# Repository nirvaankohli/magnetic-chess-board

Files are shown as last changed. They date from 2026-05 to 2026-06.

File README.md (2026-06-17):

# Magnetic Chess Board

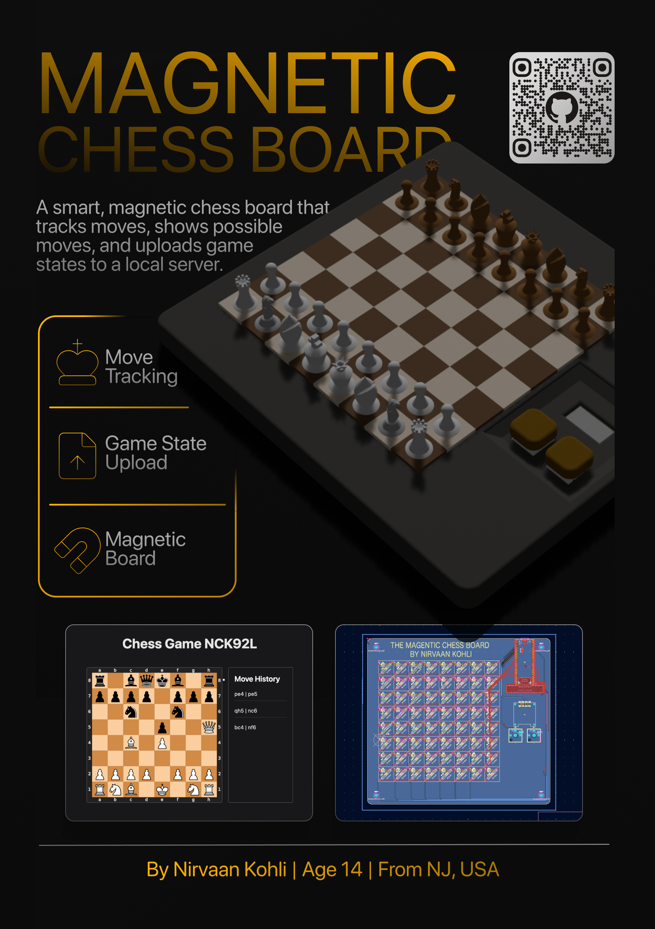
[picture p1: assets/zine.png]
Zine


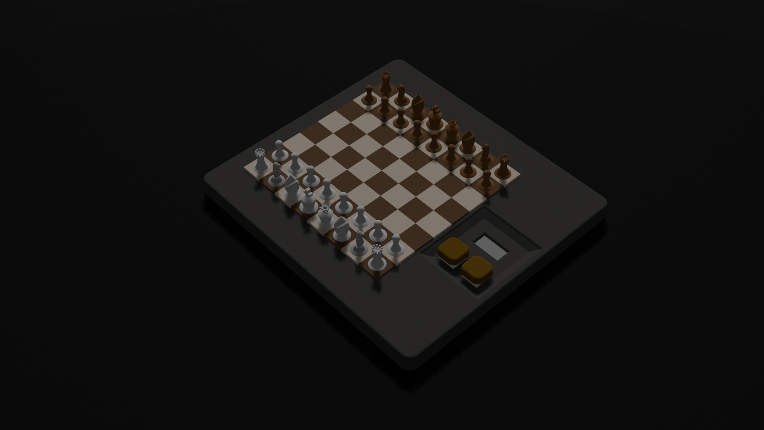
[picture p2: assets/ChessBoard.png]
Chess Board


---

## What is this project?

Magnetic Chess Board is a chessboard with electromagnetic sensors, two key switches, and an OLED display. It tracks each move you make on the board and uploads the game data to a local web server running on your device.

The chessboard itself is powered by a Raspberry Pi Pico W. The board connects wirelessly to your host device and allows you to play physically while having all the benefits of being able to analyze your gameplay later. Games are stored in json & svg format and can also be seen through the web interface on your own device.

---

## Why choose this project?

After creating [MORPH.00](https://github.com/nirvaankohli/MORPH.00/tree/main), a customizable keyboard that changes it's function, I wanted something different. Counsidently my feed showed me a chess board that can move the pieces itself. I orginally wanted to do this because of that video. However, I quickly found out the magic part of moving the pieces autonomously was to expensive. So, I settled for the next best thing, an electromagnetic chess board to analyze and track your moves. It was still such a cool idea because you are turning something physical into something digital. Additionally, let's say your friend comes voer and you play chess, you can expose the endpoint on like a server or something so both of you can look back at the game. Taking all of these things into account, I decided to choose this project. The use of this is legitimate because of the stuff I just mentioned above. 

----

This project is powered by a [Raspberry Pi Pico W](https://www.digikey.com/en/products/detail/raspberry-pi/SC0918/16608263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) running [MicroPython](https://micropython.org/download/RPI_PICO_W/) with some libraries. This microcontroller is on the top right part of the PCB so the charging port can be exposed and be close to components like the OLED and switches. 

The switches are low profile Choc V1 switches, the OLED a 0.96 Inch 128x64 OLED I2C Display Module, and all the electromagnetic sensors MKA-10110 10X18MM N/O SPST Contact Reed Switches. There is a part of this project on the host computer that hosts the web server that stores all the chess game's states and past move history. 

--- 

## CAD Renderings

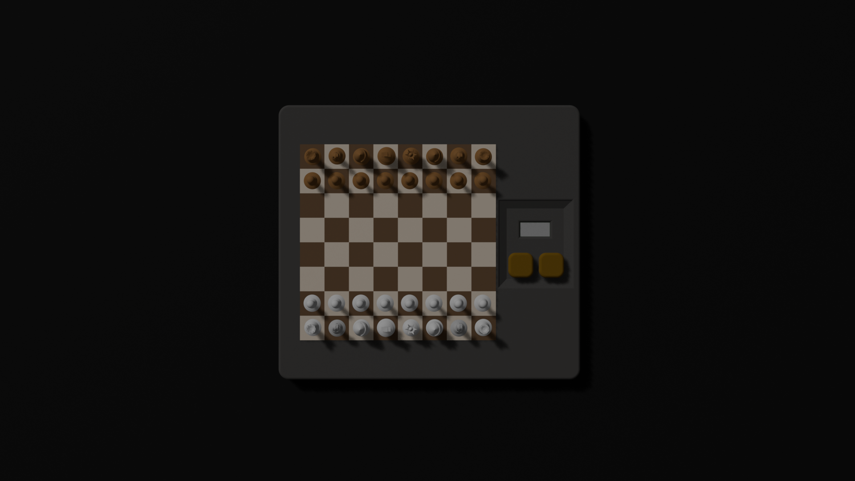
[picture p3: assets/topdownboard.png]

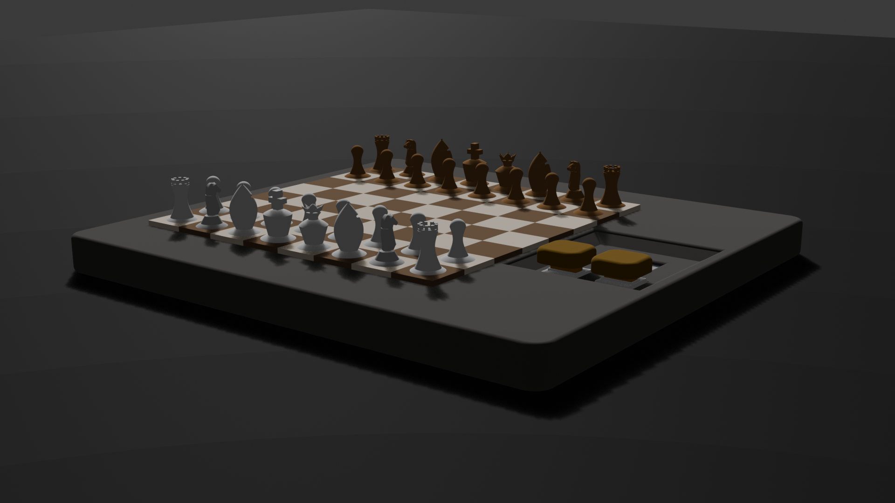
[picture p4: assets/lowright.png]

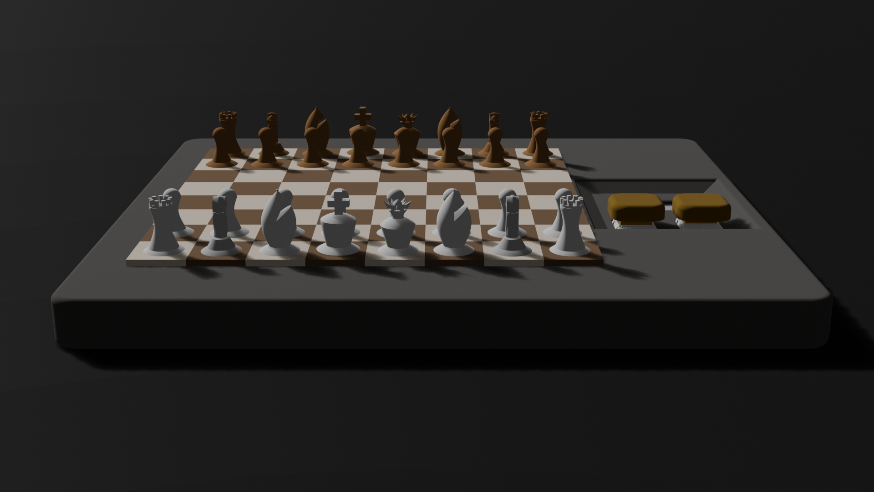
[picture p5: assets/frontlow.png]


My pieces 3D modeling is not the best, ik.

---

## PCB & Schematic

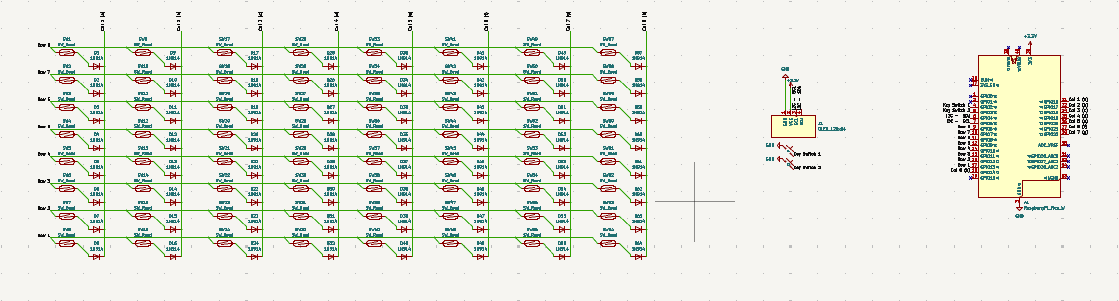
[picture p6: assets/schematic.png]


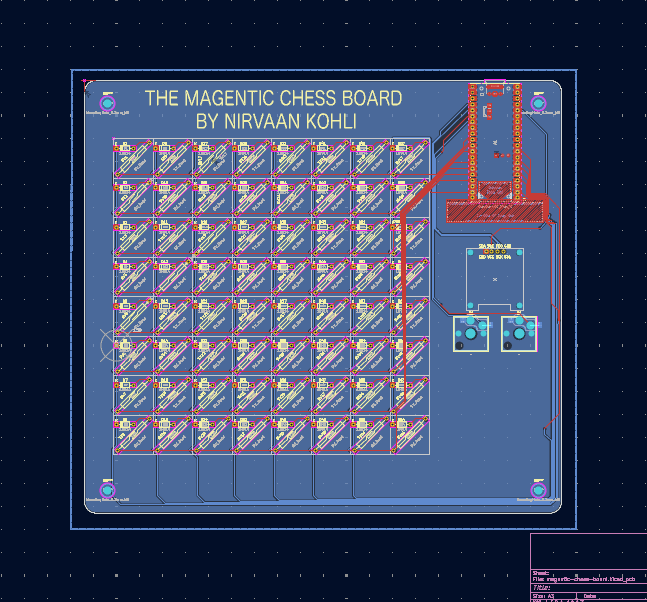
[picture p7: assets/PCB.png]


Below, is the PCB w components in multiple views.

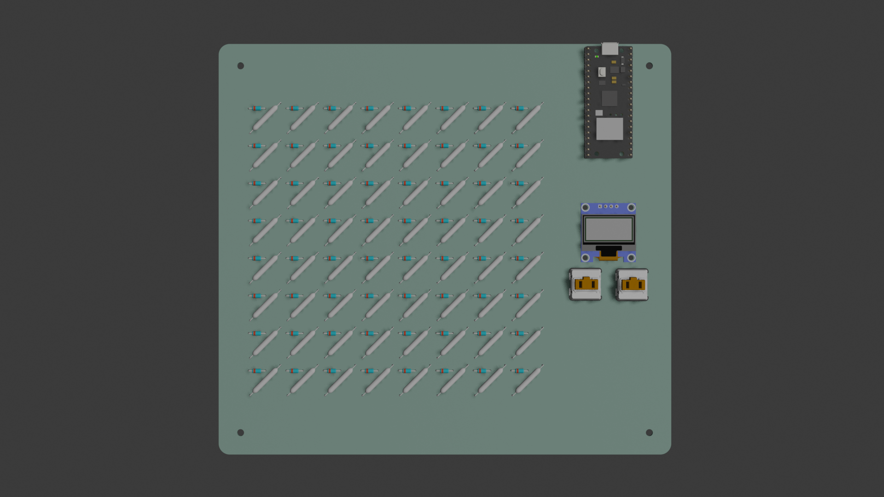
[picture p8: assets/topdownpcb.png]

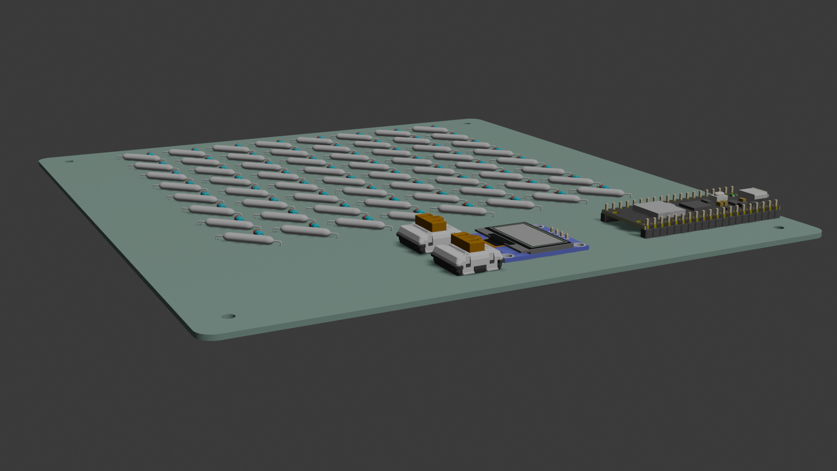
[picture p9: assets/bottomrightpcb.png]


Beautiful, right?

---

## Web Page

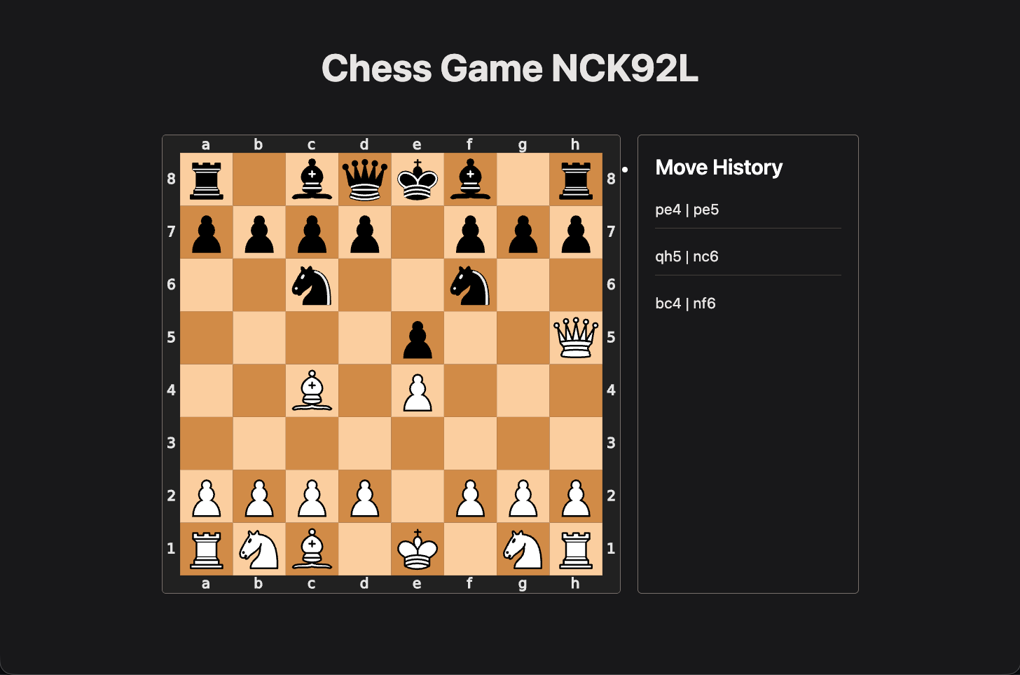
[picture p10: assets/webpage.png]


---

## How it Works

Each square on the board has a reed switch underneath it that detects wether a piece is present. A Raspberry Pi pico W scans all 8 columns and 8 rows of these switches as a key matrix, along with two buttons and an OLED display.

When a piece is moved the Pico W sends the current occupied squares to a local Flask server on the hosts computer(or anywhere). The server compares that physical board state to the saved chess game state(if the game was newly created it spins up a new one) using `python-chess`, finds the legal move that matches, and updates the game history. 

If the move is ambiguous, the OLED shows the possible moves and buttons let the player choose the correct one. After every valid move, the server saves the new board state and updates the web page so the full game can be viewed later.

---

## How To Use

1. Plug in a micro-usb cable into the Pico and the other end into your host computer
2. Install the firmware onto the Pico W(reference [this](code/pico_w/firmware.md) if not sure)
3. Download [the Thonny IDE](https://thonny.org/)
    - Click the bottom-right corner of Thonny and ensure it says MicroPython (Raspberry Pi Pico).
4. Update `code/pico_w/code/secrets.py` with:
    - your Wi-Fi SSID
    - your Wi-Fi password
    - your computer's local server address, like `http://192.168.x.x:5000`
5. In the Thonny Files sidebar, got to the "This computer" section to find the directory `code/pico_w/`. 
6. Right-click all the .py files and select `Upload to` to transfer the files to your pico.
7. Run the host server from `code/host`:
   ```bash
   flask --app app run --debug --host 0.0.0.0
    ```
8. Power on the board and wait for it to connect to WiFi.
9. Hold the white button to start a game(left).
10. Move pieces on the board as usual.
11. The white button confirms the current player's turn.
12. If the board detects multiple possible moves, use the black button to cycle through them and the white button to confirm the correct one.
13. Open the game page in your browser at:
```
http://<your-computer-ip>:5000/game/<game_id>
```
    to view the move history and current board state.

The server saves each game's state in `code/host/game_state/<game_id>.json` and `code/host/game_state/<game_id>.svg`

---

## How to Build/Assemble

Notice: You will need a way to 3D print parts for this & also have to buy all materials from [bom](bom.csv)

1. Go into `hardware/cad/3d-printed/pieces/` and print all the `.stl` files it contains. Below are which ones to print two times. 
    - Print `rook.stl`, `knight.stl`, and `bishop.stl` 2 times each for both black and white.
    - Then print both `queen.stl` and `king.stl` 1 time each for both black and white.
    - Print `disk.stl`s 16 times each for both black & white.
2. For every piece you have printed, put in the N42 magnet in it and put super glue on the remaining space and magnet.
    - Apply superglue to the bottom of a disc that matches the piece’s color, then press it face down into the extra space in the piece’s hole.
3. After you have assembled the pieces, it is time to solder on the components to the PCB board. If you do not know which components match what footprint, please reference `hardware/cad/boards/boards-w-components.step`
4. After doing that you will have to put the top frame(`hardware/cad/3d-printed/top-plate.stl`) onto the board. It should snap in. 
5. Then you will attach the bottom plate(`hardware/cad/3d-printed/bottom-plate.stl`) with a combination of the 4 screw holes(where you will put in the screw and the nut on the other side) and super glue.
6. From there you will need to print out the key caps available in `hardware/cad/3d-printed/key-cap.stl`
6. Now your chess board should be ready to go!

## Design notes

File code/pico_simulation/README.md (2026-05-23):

# Pico Simulation

Simulates PICO behaviour so we can make sure code works

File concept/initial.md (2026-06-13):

# Initial Thoughts, Plans, Description, etc.

## Different Approaches

### Criteria

- Price - Higher Score = Less Price - Weighting(Depends bc if it's really expensive it's really low, but it doesn't matter that much since fallout)
- Accuracy - Very Important
- Time - Sweet spot of 30 Hours(although all these options can be less or more depending on how big you wanna go on the software side)
- Difficulty - Sweet spot of 5-7/10 = 9/10(confusing ik)

- Magnetic Sensors
  - Summary: So the idea is that you have indivual magnetic sensors below each of 64 squares. The downside about this is that technically you can't tell what piece is which. However, you can guess pretty well based on the last game state. That is probably why I will need a 2 key switchs + OLED to communicate with the user if the board is set up or not, game updates, etc.
  - Ratings
    - Price - 6/10
    - Accuracy - 9/10
    - Time - 9/10
    - 6-7/10 - (so 8.5/10)
- CV
  - Summary: So the idea is that there is a camera of some sorts above the board(or any angle technically) that sees pieces. The problem of this is that it is inconvienient as they need to set up a camera and it might not be as accurate
  - Ratings
    - Price - 10/10
    - Accuracy - 7.5/10
    - Time - 8/10
    - 4/10 so 6/10
  
## Verdict

Obviously magnetic sensors.

Let us just figure out what stuff is needed and what it will cost :O

- Reed Switch Magentic Switch - [2x14mm MKA14103 for 0.73/5 pieces](https://www.aliexpress.us/item/3256801651270926.html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) - getting 70 bc packaging is bad so total price + shipping - about $15
- With 8 rows & Columns using key matricies
- 2 keys
- A nob
- and 1 inch oleds

https://www.magnetshop.com/neodymium-disc-magnet-42dne0608-ni.html for magents

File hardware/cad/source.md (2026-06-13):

# Onshape Link
Link

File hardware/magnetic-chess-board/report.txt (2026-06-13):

Info: X scale constrained.
Info: Y scale constrained.
Plotted to '/Users/nirvaank/Code/Hardware/fallout/magnetic-chess-board/magnetic-chess-board/hardware/magnetic-chess-board/magnetic-chess-board-F_Cu.gbr'.
Plotted to '/Users/nirvaank/Code/Hardware/fallout/magnetic-chess-board/magnetic-chess-board/hardware/magnetic-chess-board/magnetic-chess-board-B_Cu.gbr'.
Plotted to '/Users/nirvaank/Code/Hardware/fallout/magnetic-chess-board/magnetic-chess-board/hardware/magnetic-chess-board/magnetic-chess-board-F_Paste.gbr'.
Plotted to '/Users/nirvaank/Code/Hardware/fallout/magnetic-chess-board/magnetic-chess-board/hardware/magnetic-chess-board/magnetic-chess-board-B_Paste.gbr'.
Plotted to '/Users/nirvaank/Code/Hardware/fallout/magnetic-chess-board/magnetic-chess-board/hardware/magnetic-chess-board/magnetic-chess-board-F_Silkscreen.gbr'.
Plotted to '/Users/nirvaank/Code/Hardware/fallout/magnetic-chess-board/magnetic-chess-board/hardware/magnetic-chess-board/magnetic-chess-board-B_Silkscreen.gbr'.
Plotted to '/Users/nirvaank/Code/Hardware/fallout/magnetic-chess-board/magnetic-chess-board/hardware/magnetic-chess-board/magnetic-chess-board-F_Mask.gbr'.
Plotted to '/Users/nirvaank/Code/Hardware/fallout/magnetic-chess-board/magnetic-chess-board/hardware/magnetic-chess-board/magnetic-chess-board-B_Mask.gbr'.
Plotted to '/Users/nirvaank/Code/Hardware/fallout/magnetic-chess-board/magnetic-chess-board/hardware/magnetic-chess-board/magnetic-chess-board-Edge_Cuts.gbr'.
Created Gerber job file '/Users/nirvaank/Code/Hardware/fallout/magnetic-chess-board/magnetic-chess-board/hardware/magnetic-chess-board/magnetic-chess-board-job.gbrjob'.
Info: Done.

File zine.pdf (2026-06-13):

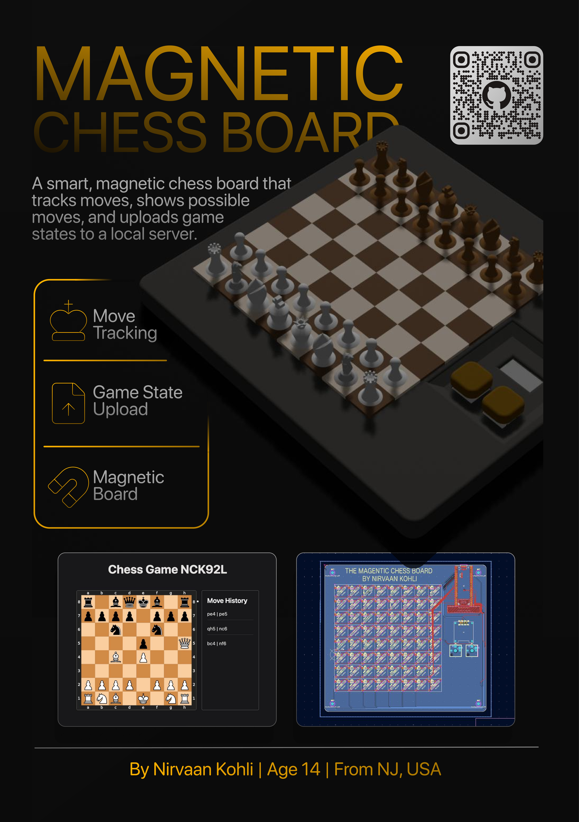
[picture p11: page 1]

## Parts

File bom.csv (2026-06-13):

Part Name | Part Number | Qty | Unit | Qty of Product | Unit Cost | Total Cost(w/o shipping) | Total/Final Cost(with shipping) | url
M3 x 5mm Socket Flat Head Screws | M3-0.5X5-FH-A2 | 4 | pcs | 1 | $3.75 | $4.69 | $4.69 | https://www.ebay.com/itm/297651673962?var=595006893034
Loctite Essentials Super Glue Liquid Tubes (0.11 oz tubes) | LOC-ESSENTIAL-3G-4PK-SG-LQ-H-TBE-12PG | 1 | tube | 1 | $0.72 | $2.88 | $9.87 | https://www.walmart.com/ip/seort/15670220393
N42 Neodymium Disc Magnet | 42DNE0608-NI | 64 | pcs | 64 | $19.20 | $19.20 | $19.20 | https://www.magnetshop.com/neodymium-disc-magnet-42dne0608-ni.html
Kailh 1350 Choc V1 Brown Switch(10 pcs) | CPG135001D02 | 2 | pcs | 10 | $1.48 | $7.40 | $7.40 | https://www.aliexpress.us/item/3256811626047380.html?curPageLogUid=gMyMy9GAItqi
20 PCS MKA-10110 10X18MM Magnetic Sensor N/O SPST Contact Reed Switches | CPG135001S30 | 64 | pcs | 4 | $22.05 | $27.56 | $33.30 | https://www.aliexpress.us/item/3256811899463529.html?curPageLogUid=F80mUPvjcfot
PLA 3D Printer Filament (1.75mm, 1kg Spool, Black) | B07XG3RM58 | 1 | spool | 1 | $13.99 | $13.99 | $13.99 | https://www.amazon.com/Printer-Filament-SUNLU-Dimensional-Accuracy/dp/B07XG3RM58?rnid=2661611011
0.96 Inch OLED Display Module (I2C/IIC/SPI Serial 128X64, SSD1315 Driver) | 1005009059402520 | 1 | pcs | 1 | $1.49 | $1.49 | $6.72 | https://www.aliexpress.us/item/3256808873087768.html?curPageLogUid=4nQOOlsmmnd3
RASPBERRY PI PICO W RP2040 | SC0918 | 1 | pcs | 1 | $6.00 | $6.00 | $15.09 | https://www.digikey.com/en/products/detail/raspberry-pi/SC0918/16608263?gclsrc=aw.ds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
CONN HEADER VERT 20POS 2.54MM | 10129378-920003BLF | 2 | pcs | 2 | $1.02 | $1.02 | $9.87 | https://www.digikey.com/en/products/detail/amphenol-icc-fci-/10129378-920003BLF/7915971?gclsrc=aw.ds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
Stainless Steel Hexagon Nuts (Fasteners Replacement) | B0DRF8FF5Z | 4 | pcs | 1 | $0.02 | $4.99 | $4.99 | https://www.amazon.com/Yinpecly-Stainless-Hexagon-Fasteners-Replacement/dp/B0DRF8FF5Z?rnid=386419011
PCB(JLCPCB) - 207.1 x 187.96 | None | 1 | pcs | 1 | $19.70 | $19.70 | $29.78 | https://cart.jlcpcb.com/quote?rand=0.17716329742027792

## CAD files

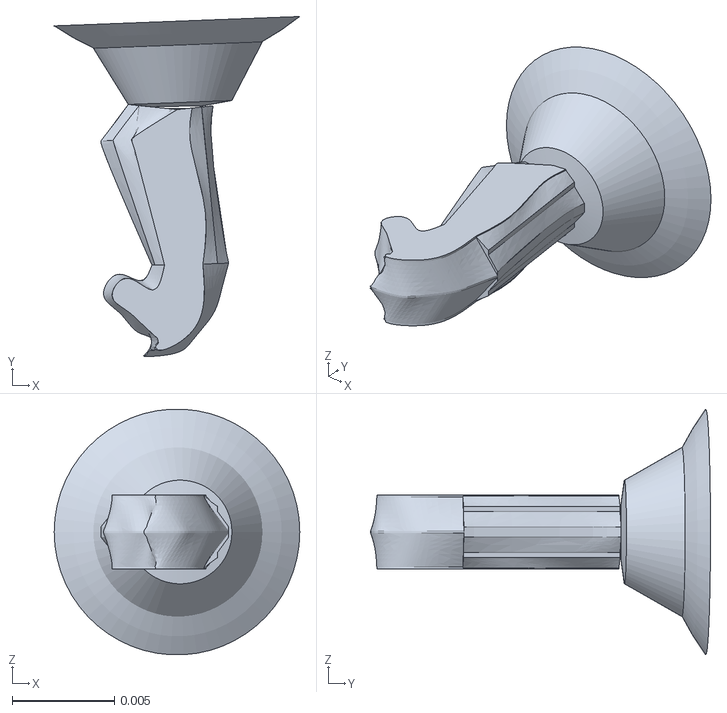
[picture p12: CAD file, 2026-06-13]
hardware/cad/3d-printed/pieces/knight.stl
0.012 x 0.0166 x 0.012

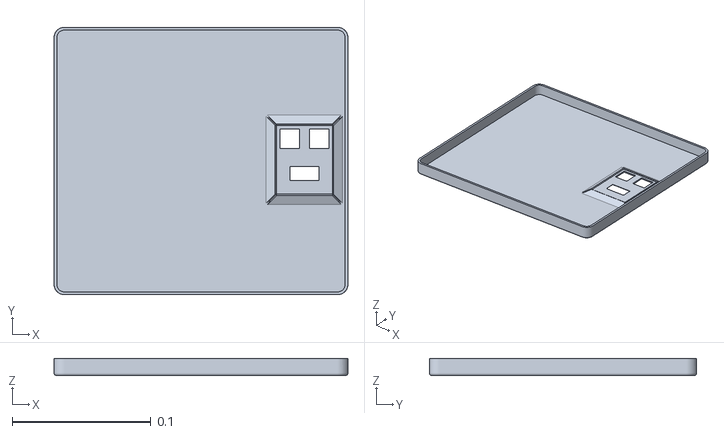
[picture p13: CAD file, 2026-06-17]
hardware/cad/3d-printed/top-plate.stl
0.212 x 0.193 x 0.0125

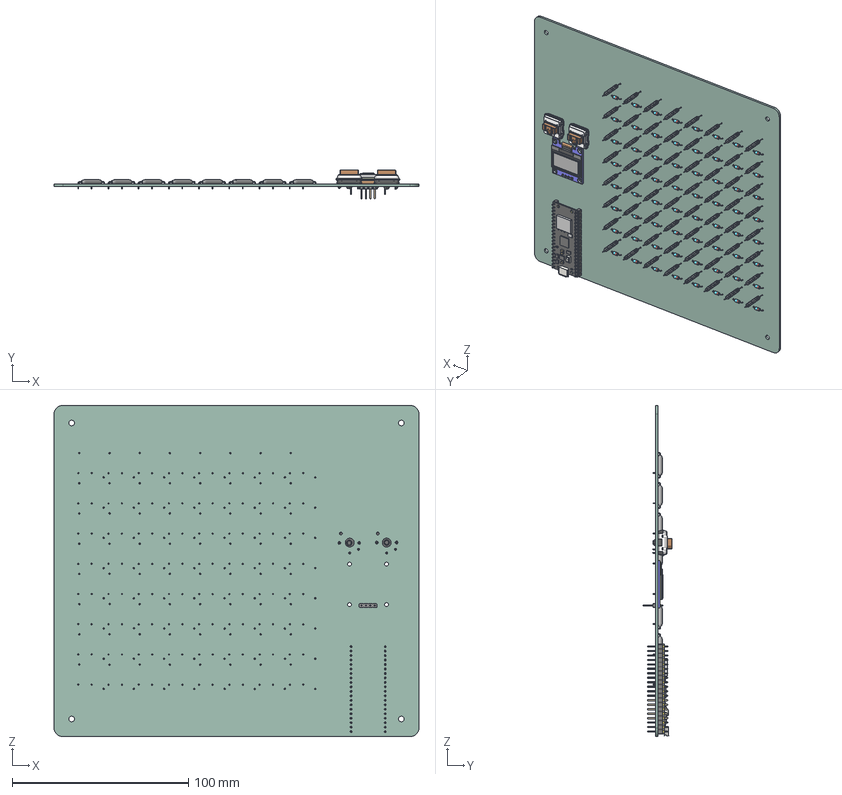
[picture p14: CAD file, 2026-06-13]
hardware/cad/boards/boards-w-components.step
207.1 x 16.6 x 188.0 mm
D_DO-35_SOD27_P7.62mm_Horizontal x 128
magnetic-chess-board_PCB
Root x 64
OLED x 50
Choc_V1 x 10
RaspberryPi_Pico_W_Module_KiCad
PinHeader_1x20_P2.54mm_Vertical x 2

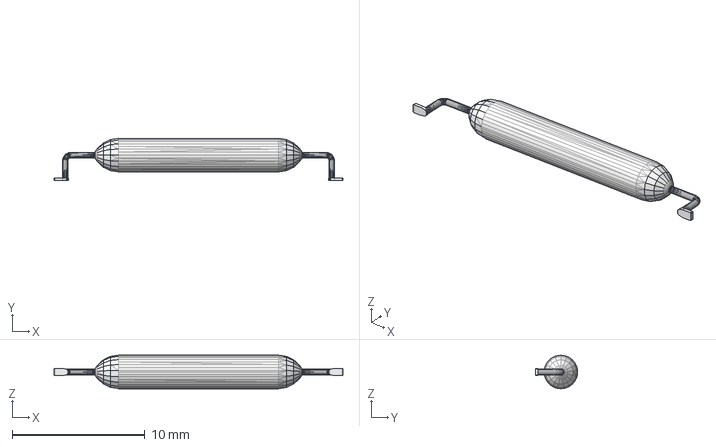
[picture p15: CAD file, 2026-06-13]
hardware/cad/components/MKA-14103.step
21.8 x 3.19 x 2.53 mm

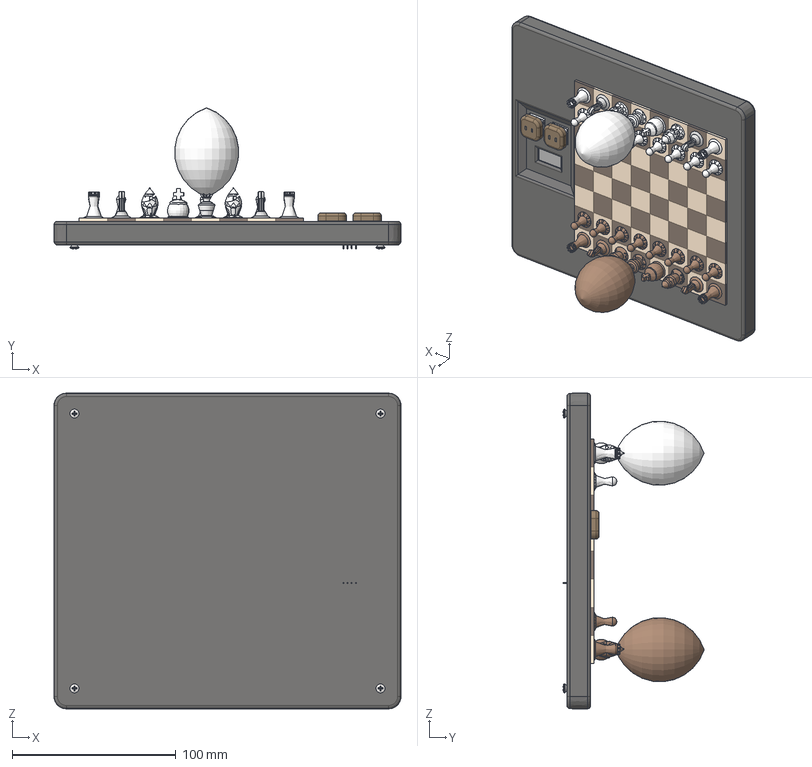
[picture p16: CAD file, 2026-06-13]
hardware/cad/final-build.step
212.1 x 86.5 x 193.0 mm
D_DO-35_SOD27_P7.62mm_Horizontal x 128
magnetic-chess-board_PCB
Root x 64
OLED x 50
Brown Square x 32
Tan Square x 32
Choc_V1 x 10
RaspberryPi_Pico_W_Module_KiCad
m3-5mm x 4
PinHeader_1x20_P2.54mm_Vertical x 2

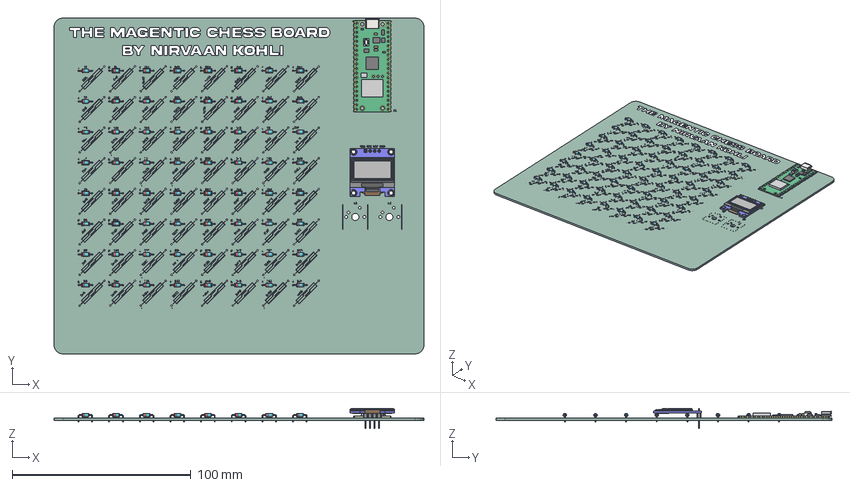
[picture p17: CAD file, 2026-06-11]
hardware/magnetic-chess-board/board.step
207.1 x 188.0 x 11.3 mm
D_DO-35_SOD27_P7.62mm_Horizontal x 64
OLED
RaspberryPi_Pico_W_Module_KiCad
magnetic-chess-board_silkscreen
magnetic-chess-board_PCB

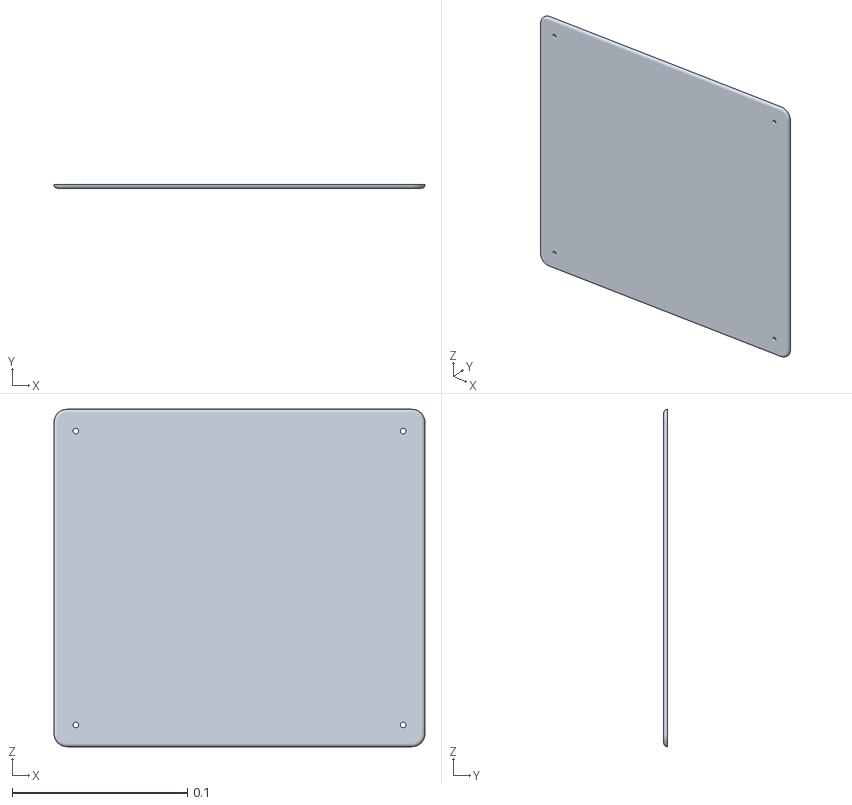
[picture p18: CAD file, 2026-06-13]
hardware/cad/3d-printed/bottom-plate.stl
0.212 x 0.002 x 0.193

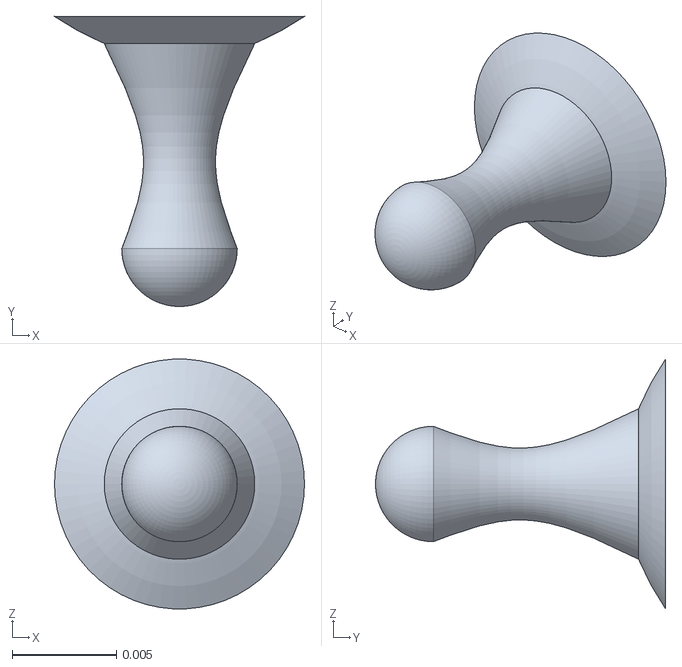
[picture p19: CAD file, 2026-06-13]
hardware/cad/3d-printed/pieces/pawn.stl
0.012 x 0.0139 x 0.012

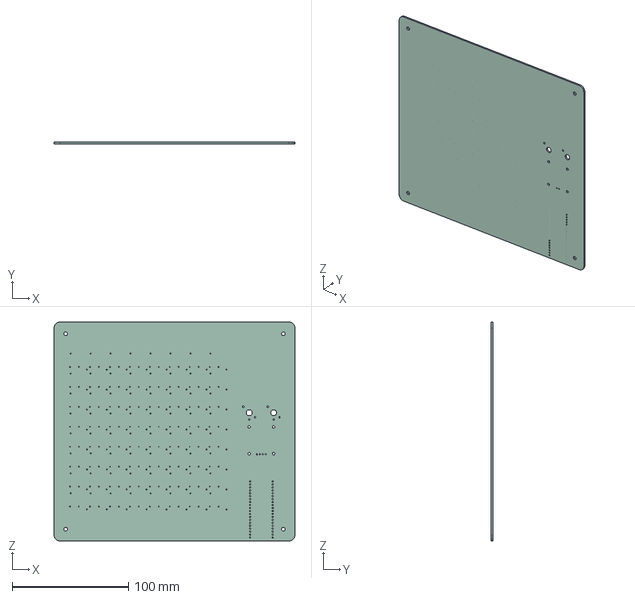
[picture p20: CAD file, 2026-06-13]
hardware/cad/boards/board.step
207.1 x 1.51 x 188.0 mm

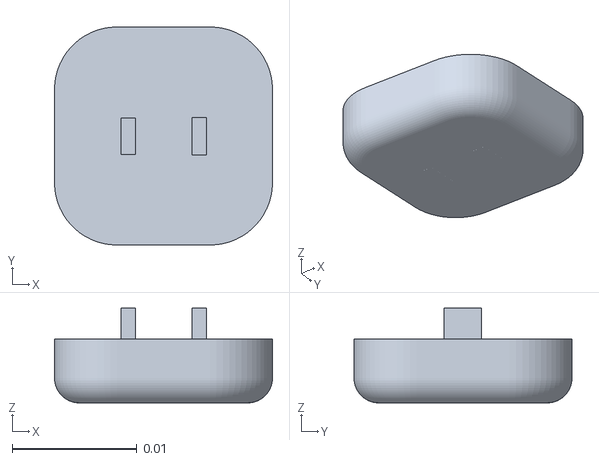
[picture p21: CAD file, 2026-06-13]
hardware/cad/3d-printed/key-cap.stl
0.0175 x 0.0175 x 0.00763

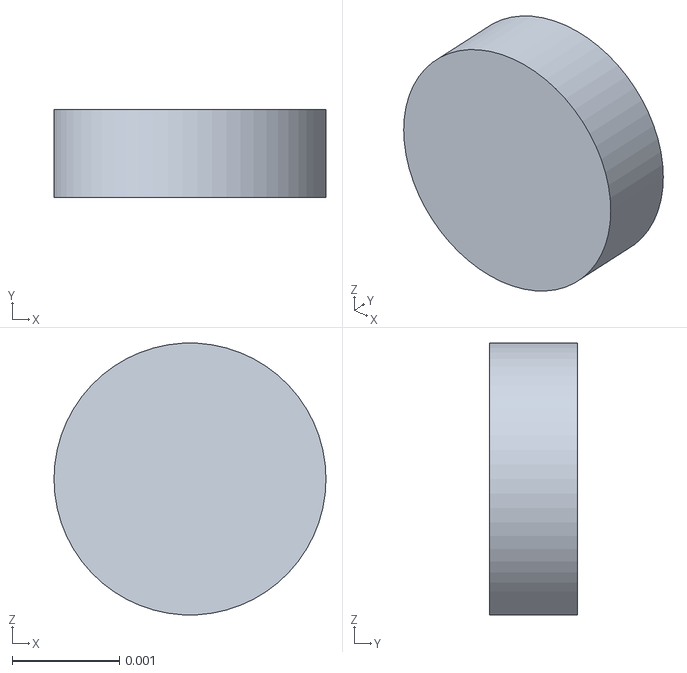
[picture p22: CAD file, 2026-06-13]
hardware/cad/3d-printed/pieces/disk.stl
0.00254 x 0.000825 x 0.00254

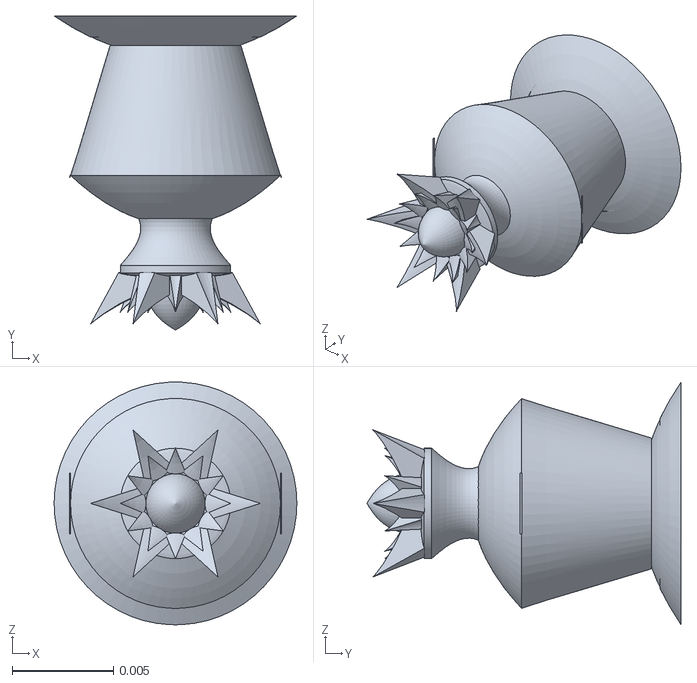
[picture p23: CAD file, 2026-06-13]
hardware/cad/3d-printed/pieces/queen.stl
0.012 x 0.0155 x 0.012

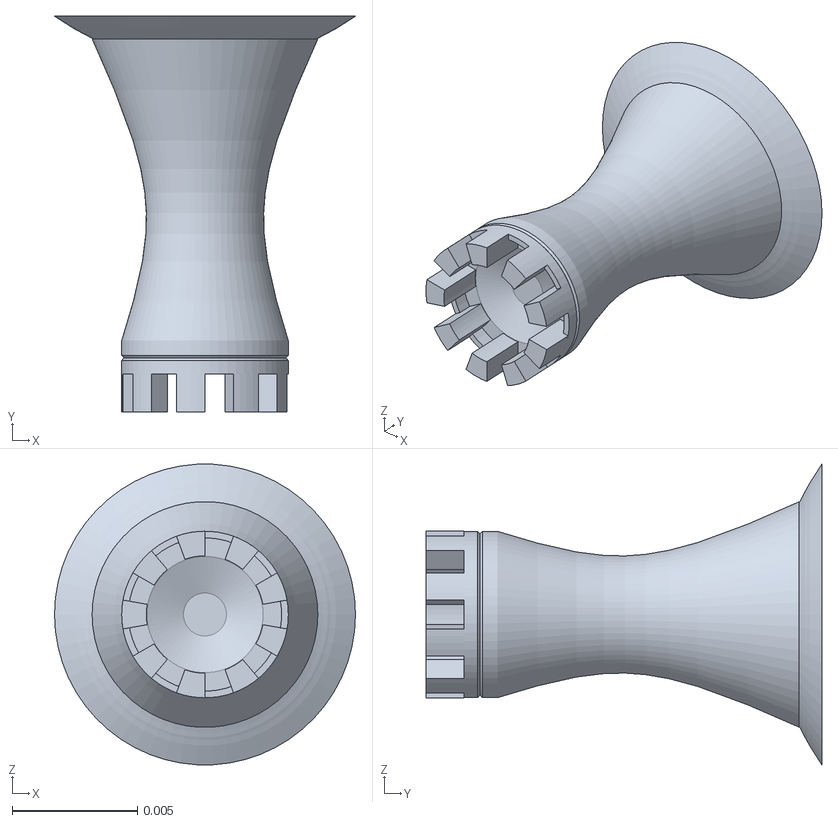
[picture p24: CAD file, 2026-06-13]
hardware/cad/3d-printed/pieces/rook.stl
0.012 x 0.0158 x 0.012

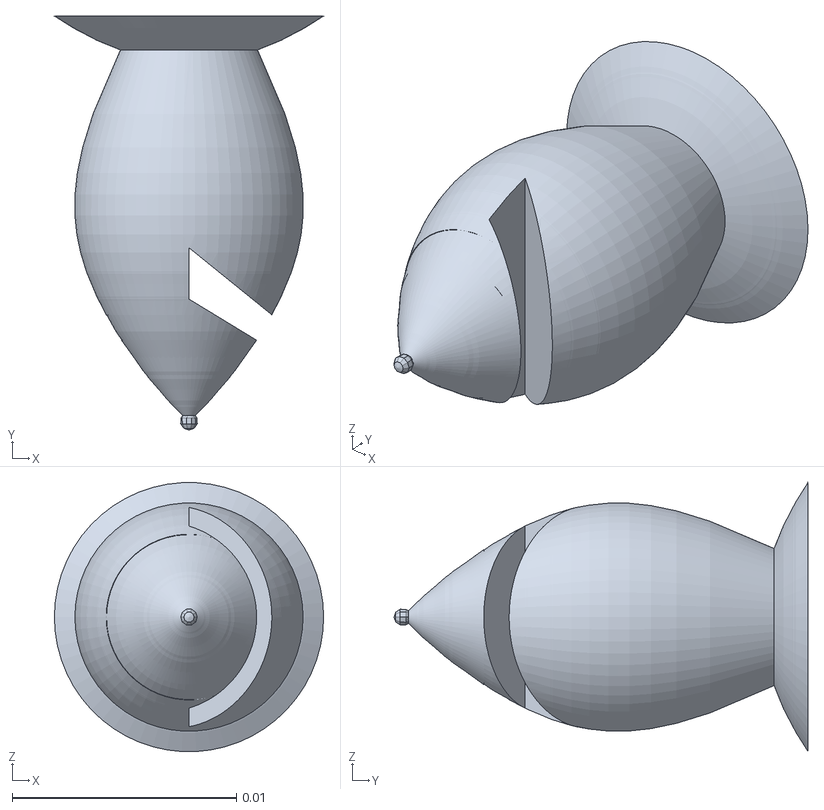
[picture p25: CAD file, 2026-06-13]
hardware/cad/3d-printed/pieces/bishop.stl
0.012 x 0.0185 x 0.012

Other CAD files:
hardware/magnetic-chess-board/board_only.step
hardware/cad/3d-printed/pieces/king.stl
hardware/cad/components/m3-5mm-screw.step

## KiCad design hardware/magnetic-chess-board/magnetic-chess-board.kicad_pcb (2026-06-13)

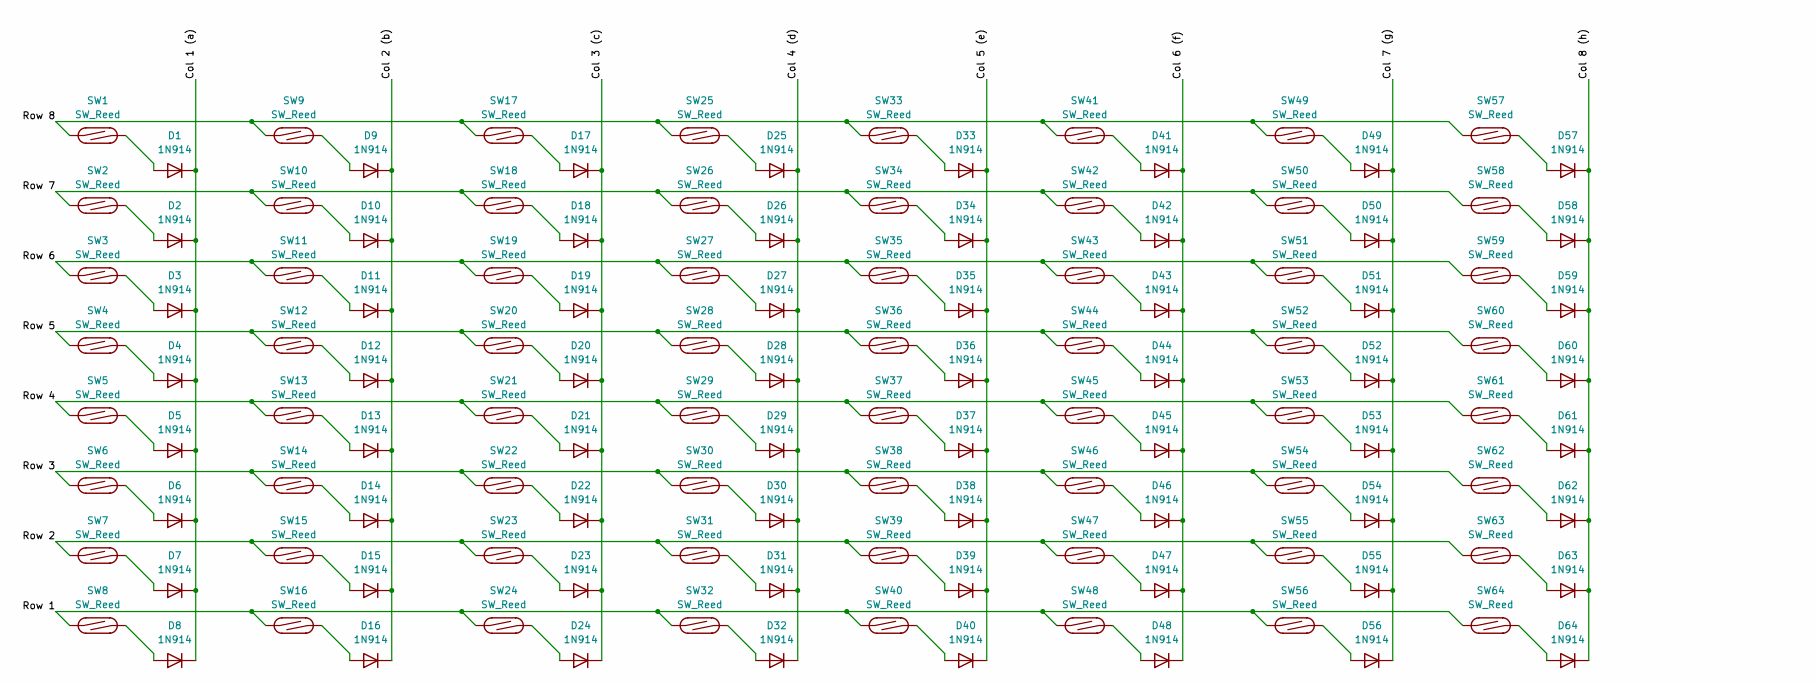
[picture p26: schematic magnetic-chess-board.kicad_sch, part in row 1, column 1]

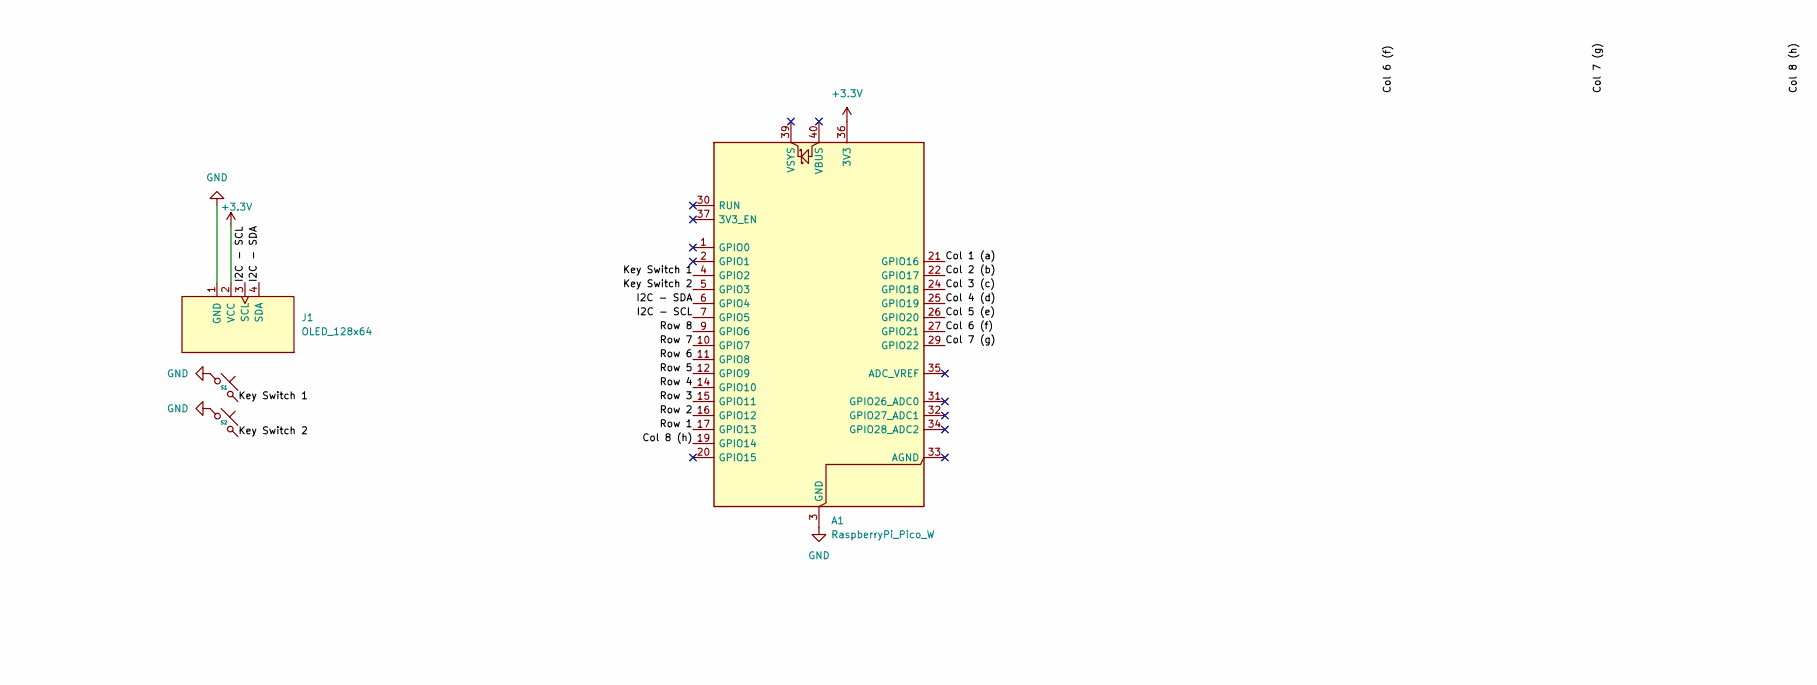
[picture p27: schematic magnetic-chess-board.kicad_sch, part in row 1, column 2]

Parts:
A1: RaspberryPi_Pico_W; RaspberryPi_Pico_W_SMD
D1, D2, D3, D4, D5, D6, D7, D8, D9, D10, D11, D12, D13, D14, D15, D16, D17, D18, D19, D20, D21, D22, D23, D24, D25, D26, D27, D28, D29, D30, D31, D32, D33, D34, D35, D36, D37, D38, D39, D40, D41, D42, D43, D44, D45, D46, D47, D48, D49, D50, D51, D52, D53, D54, D55, D56, D57, D58, D59, D60, D61, D62, D63, D64: 1N914; D_DO-35_SOD27_P7.62mm_Horizontal
J1: OLED_128x64
S1, S2: SW_Hotswap_Kailh_Choc_V1
SW1, SW2, SW3, SW4, SW5, SW6, SW7, SW8, SW9, SW10, SW11, SW12, SW13, SW14, SW15, SW16, SW17, SW18, SW19, SW20, SW21, SW22, SW23, SW24, SW25, SW26, SW27, SW28, SW29, SW30, SW31, SW32, SW33, SW34, SW35, SW36, SW37, SW38, SW39, SW40, SW41, SW42, SW43, SW44, SW45, SW46, SW47, SW48, SW49, SW50, SW51, SW52, SW53, SW54, SW55, SW56, SW57, SW58, SW59, SW60, SW61, SW62, SW63, SW64: SW_Reed; MKA-14103

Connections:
+3.3V: A1.36 (3V3), J1.2 (VCC)
/Col 1 (a): A1.21 (GPIO16), D1.1 (K), D2.1 (K), D3.1 (K), D4.1 (K), D5.1 (K), D6.1 (K), D7.1 (K), D8.1 (K)
/Col 2 (b): A1.22 (GPIO17), D9.1 (K), D10.1 (K), D11.1 (K), D12.1 (K), D13.1 (K), D14.1 (K), D15.1 (K), D16.1 (K)
/Col 3 (c): A1.24 (GPIO18), D17.1 (K), D18.1 (K), D19.1 (K), D20.1 (K), D21.1 (K), D22.1 (K), D23.1 (K), D24.1 (K)
/Col 4 (d): A1.25 (GPIO19), D25.1 (K), D26.1 (K), D27.1 (K), D28.1 (K), D29.1 (K), D30.1 (K), D31.1 (K), D32.1 (K)
/Col 5 (e): A1.26 (GPIO20), D33.1 (K), D34.1 (K), D35.1 (K), D36.1 (K), D37.1 (K), D38.1 (K), D39.1 (K), D40.1 (K)
/Col 6 (f): A1.27 (GPIO21), D41.1 (K), D42.1 (K), D43.1 (K), D44.1 (K), D45.1 (K), D46.1 (K), D47.1 (K), D48.1 (K)
/Col 7 (g): A1.29 (GPIO22), D49.1 (K), D50.1 (K), D51.1 (K), D52.1 (K), D53.1 (K), D54.1 (K), D55.1 (K), D56.1 (K)
/Col 8 (h): A1.19 (GPIO14), D57.1 (K), D58.1 (K), D59.1 (K), D60.1 (K), D61.1 (K), D62.1 (K), D63.1 (K), D64.1 (K)
/I2C - SCL: A1.7 (GPIO5), J1.3 (SCL)
/I2C - SDA: A1.6 (GPIO4), J1.4 (SDA)
/Key Switch 1: A1.4 (GPIO2), S1.2
/Key Switch 2: A1.5 (GPIO3), S2.2
/Row 1: A1.17 (GPIO13), SW8.1, SW16.1, SW24.1, SW32.1, SW40.1, SW48.1, SW56.1, SW64.1
/Row 2: A1.16 (GPIO12), SW7.1, SW15.1, SW23.1, SW31.1, SW39.1, SW47.1, SW55.1, SW63.1
/Row 3: A1.15 (GPIO11), SW6.1, SW14.1, SW22.1, SW30.1, SW38.1, SW46.1, SW54.1, SW62.1
/Row 4: A1.14 (GPIO10), SW5.1, SW13.1, SW21.1, SW29.1, SW37.1, SW45.1, SW53.1, SW61.1
/Row 5: A1.12 (GPIO9), SW4.1, SW12.1, SW20.1, SW28.1, SW36.1, SW44.1, SW52.1, SW60.1
/Row 6: A1.11 (GPIO8), SW3.1, SW11.1, SW19.1, SW27.1, SW35.1, SW43.1, SW51.1, SW59.1
/Row 7: A1.10 (GPIO7), SW2.1, SW10.1, SW18.1, SW26.1, SW34.1, SW42.1, SW50.1, SW58.1
/Row 8: A1.9 (GPIO6), SW1.1, SW9.1, SW17.1, SW25.1, SW33.1, SW41.1, SW49.1, SW57.1
GND: A1.3 (GND), A1.8 (GND), A1.13 (GND), A1.18 (GND), A1.23 (GND), A1.28 (GND), A1.38 (GND), J1.1 (GND), S1.1, S2.1
unnamed: D1.2 (A), SW1.2
unnamed: D2.2 (A), SW2.2
unnamed: D3.2 (A), SW3.2
unnamed: D4.2 (A), SW4.2
unnamed: D5.2 (A), SW5.2
unnamed: D6.2 (A), SW6.2
unnamed: D7.2 (A), SW7.2
unnamed: D8.2 (A), SW8.2
unnamed: D9.2 (A), SW9.2
unnamed: D10.2 (A), SW10.2
unnamed: D11.2 (A), SW11.2
unnamed: D12.2 (A), SW12.2
unnamed: D13.2 (A), SW13.2
unnamed: D14.2 (A), SW14.2
unnamed: D15.2 (A), SW15.2
unnamed: D16.2 (A), SW16.2
unnamed: D17.2 (A), SW17.2
unnamed: D18.2 (A), SW18.2
unnamed: D19.2 (A), SW19.2
unnamed: D20.2 (A), SW20.2
unnamed: D21.2 (A), SW21.2
unnamed: D22.2 (A), SW22.2
unnamed: D23.2 (A), SW23.2
unnamed: D24.2 (A), SW24.2
unnamed: D25.2 (A), SW25.2
unnamed: D26.2 (A), SW26.2
unnamed: D27.2 (A), SW27.2
unnamed: D28.2 (A), SW28.2
unnamed: D29.2 (A), SW29.2
unnamed: D30.2 (A), SW30.2
unnamed: D31.2 (A), SW31.2
unnamed: D32.2 (A), SW32.2
unnamed: D33.2 (A), SW33.2
unnamed: D34.2 (A), SW34.2
unnamed: D35.2 (A), SW35.2
unnamed: D36.2 (A), SW36.2
unnamed: D37.2 (A), SW37.2
unnamed: D38.2 (A), SW38.2
unnamed: D39.2 (A), SW39.2
unnamed: D40.2 (A), SW40.2
unnamed: D41.2 (A), SW41.2
unnamed: D42.2 (A), SW42.2
unnamed: D43.2 (A), SW43.2
unnamed: D44.2 (A), SW44.2
unnamed: D45.2 (A), SW45.2
unnamed: D46.2 (A), SW46.2
unnamed: D47.2 (A), SW47.2
unnamed: D48.2 (A), SW48.2
unnamed: D49.2 (A), SW49.2
unnamed: D50.2 (A), SW50.2
unnamed: D51.2 (A), SW51.2
unnamed: D52.2 (A), SW52.2
unnamed: D53.2 (A), SW53.2
unnamed: D54.2 (A), SW54.2
unnamed: D55.2 (A), SW55.2
unnamed: D56.2 (A), SW56.2
unnamed: D57.2 (A), SW57.2
unnamed: D58.2 (A), SW58.2
unnamed: D59.2 (A), SW59.2
unnamed: D60.2 (A), SW60.2
unnamed: D61.2 (A), SW61.2
unnamed: D62.2 (A), SW62.2
unnamed: D63.2 (A), SW63.2
unnamed: D64.2 (A), SW64.2

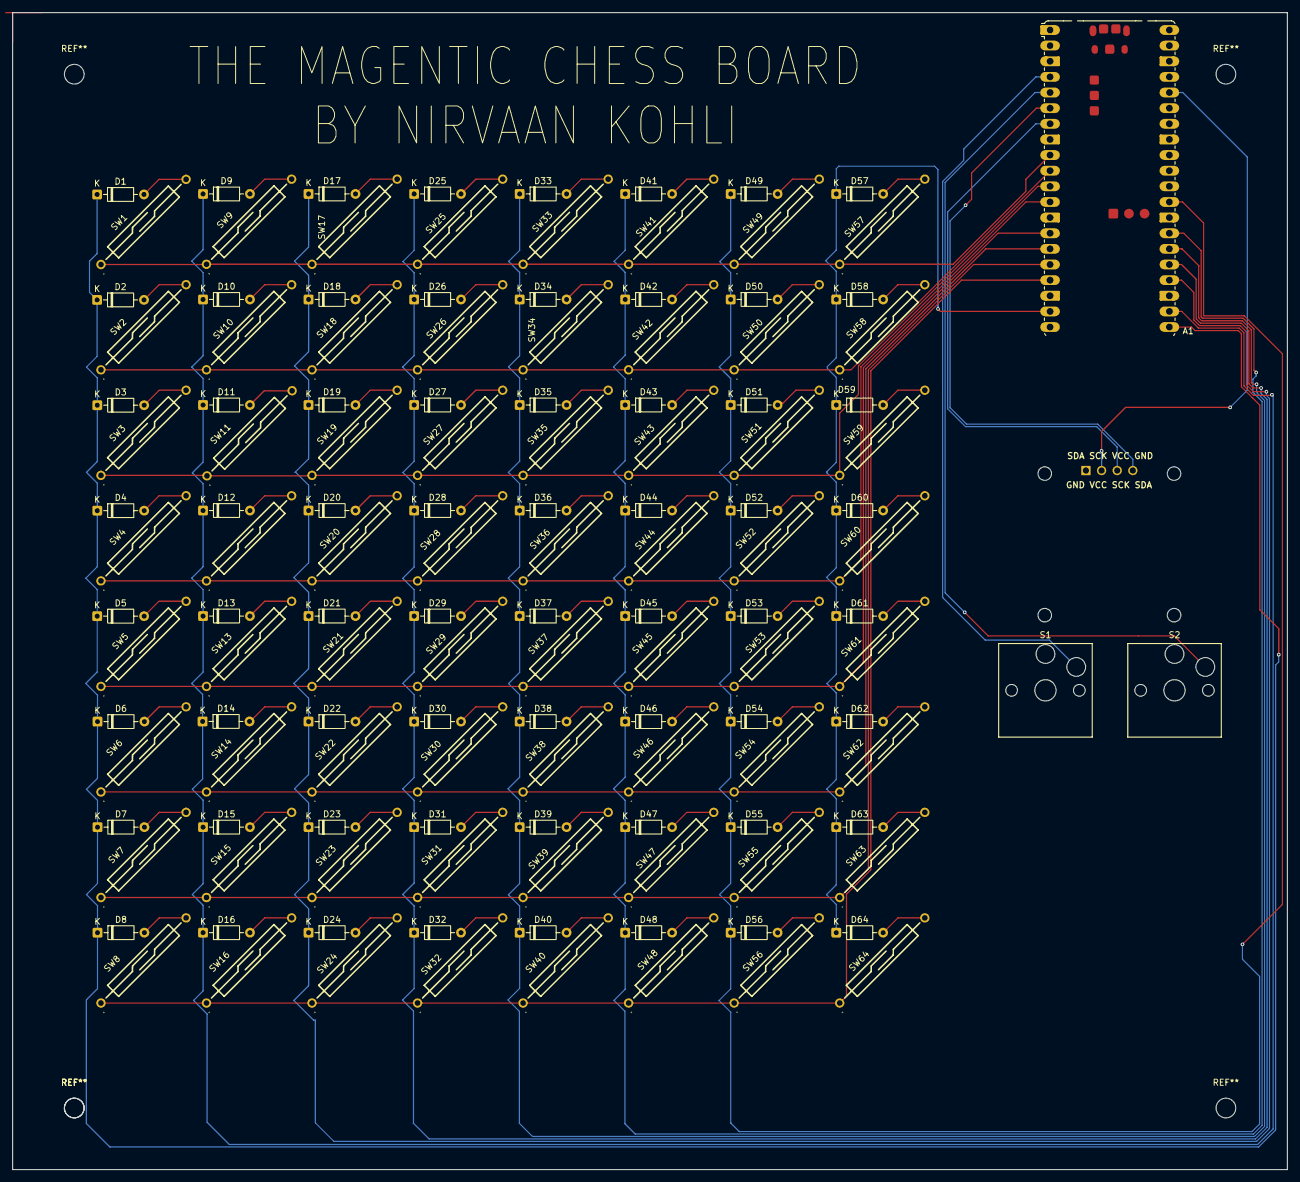
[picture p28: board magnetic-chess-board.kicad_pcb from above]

Board: 2 copper layers, 207.1 x 188.0 mm, 132 parts (0 on the bottom side), 86 nets.

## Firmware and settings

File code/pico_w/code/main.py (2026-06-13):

import network
import time
from machine import Pin, ADC, I2C
import ssd1306
from secrets import ssid, password, server_url
import random
import urequests

global move

move = "w"

wlan = network.WLAN(network.STA_IF)
wlan.active(True)
wlan.connect(ssid, password)

endpoint = "/pressed_keys"

white_button = [Pin(2, Pin.IN, Pin.PULL_DOWN), 0, 200]
black_button = [Pin(3, Pin.IN, Pin.PULL_DOWN), 0, 200]

rows_reed_switch_pins = list(reversed([6, 7, 8, 9, 10, 11, 12, 13]))
columns_reed_switch_pins = [16, 17, 18, 19, 20, 21, 22, 14]

i2c = I2C(0, scl=Pin(5), sda=Pin(4))

def scan_matrix(row_pins, col_pins):

    active_keys = []
    for row_idx, row_pin in enumerate(row_pins):

        row_pin.value(1)

        for col_idx, col_pin in enumerate(col_pins):

            if col_pin.value() == 1:
                active_keys.append([row_idx, col_idx])

        row_pin.value(0)

    return active_keys


def create_matrix(rows: int, columns: int):

    chess_rows = map(lambda x: str(x), [1, 2, 3, 4, 5, 6, 7, 8])
    chess_columns = ["a", "b", "c", "d", "e", "f", "g", "h"]

    matrix = []

    for row in chess_rows:

        columns = []

        for column in chess_columns:

            columns.append(column + row)

        matrix.append(columns)

    return matrix


def convert_numbers_to_pins(numbers, pins=[Pin.IN, Pin.PULL_DOWN]):
    return [Pin(x, *pins) for x in numbers]


def handle_key_press(pressed_keys, matrix, game_id, chose_key=None):


    global move

    response = urequests.post(
        server_url + endpoint + f"?game_id={game_id}",
        json={"pressed_keys": pressed_keys, "matrix": matrix, "timestamp": time.time(), "chose_key": chose_key},
    )

    if response.status_code == 200:

        
        data = response.json()

        response.close()

        if data.get("status") == "success":

            if data.get("white_to_move"):

                move = "w"

            else:
                
                move = "b"
        
        return data


def handle_button(type_button):

    if type_button == move:

        return True
    
    return False

def handle_next_move(current_pressed, matrix, display, white_button, black_button, game_id, chose_key=None):

    result = handle_key_press(current_pressed, matrix, game_id=game_id, chose_key=chose_key)

    if result.get("status") == "success":

        display.fill(0)
        display.text("Move applied!", 0, 0)
        display.show()

    elif result.get("status") == "error":

        display.fill(0)
        display.text("Error applying move", 0, 0)
        display.text("Invalid move. Try again.", 0, 10)
        display.show()

    elif result.get("status") == "ambiguous":

        display.fill(0)
        display.text("Multiple moves detected!", 0, 0)
        display.text("Select a move:", 0, 10)
        
        list_of_moves = result.get("possible_moves", [])

        for idx, move in enumerate(list_of_moves):

            display.text(f"{idx+1}. {move}", 0, 20 + idx*10)
        

        display.show()

        indicator = 0

        while True:
            current_time = time.ticks_ms()

            if white_button[0].value() == 0 and time.ticks_diff(current_time, white_button[1]) > white_button[2]:

                white_button[1] = current_time

                handle_next_move(current_pressed, matrix, display, white_button, black_button, chose_key=list_of_moves[indicator])

                break

            if black_button[0].value() == 0 and time.ticks_diff(current_time, black_button[1]) > black_button[2]:

                indicator = (indicator + 1) % len(list_of_moves)
                black_button[1] = current_time


matrix = create_matrix(8, 8)

display = ssd1306.SSD1306_I2C(128, 64, i2c)

row_pins = convert_numbers_to_pins(rows_reed_switch_pins, [Pin.OUT])
column_pins = convert_numbers_to_pins(columns_reed_switch_pins, [Pin.IN, Pin.PULL_DOWN])

def play_game():

    last_pressed = []

    # get initial state 

    response = urequests.post(server_url + "/make_game")
    game_id = response.json().get("game_id")
    response.close()

    while True:

        current_time = time.ticks_ms()
        correct_button_pressed = False

        if white_button[0].value() == 0 and time.ticks_diff(current_time, white_button[1]) > white_button[2]:

            correct_button_pressed = handle_button("w")
            white_button[1] = time.ticks_ms()

        if black_button[0].value() == 0 and time.ticks_diff(current_time, black_button[1]) > black_button[2]:
            
            correct_button_pressed = handle_button("b")
            black_button[1] = time.ticks_ms()

        current_pressed = scan_matrix(row_pins, column_pins)

        if current_pressed != last_pressed and correct_button_pressed:

            if current_pressed:

                handle_next_move(current_pressed, matrix, display, white_button, black_button, game_id)
                last_pressed = current_pressed

        if not current_pressed:
            last_pressed = current_pressed





def main():

    press_time = 0
    held = False

    while not wlan.isconnected() and wlan.status() >= 0:

        print("Waiting to connect...")
        time.sleep(1)

    # connected, now going to confirm start of game

    display.fill(0)
    display.text("Connected to WiFi!", 0, 0)
    display.show()
    time.sleep(2)

    while True:

        display.fill(0)
        display.text("Start game?", 0, 0)
        display.text("Hold white button to start", 0, 10)
        display.show()

        while True:

            current_time = time.ticks_ms()

            # hold 2 seconds logic

            if white_button[0].value() == 0:

                if press_time == 0:
                    press_time = time.ticks_ms()
                    
                elif not held and time.ticks_diff(time.ticks_ms(), press_time) > 2000:

                    held = True
                    play_game()
                    break

            else:
                    
                press_time = 0
                held = False

            
            

if __name__ == "__main__":

    main()

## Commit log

2026-05-20 Refactor code structure for improved readability and maintainability
    [board_only.step, magnetic-chess-board.kicad_pcb, magnetic-chess-board.kicad_sch]
2026-05-24 Sun May 24 - Fixed handling of 2+ possiblities on move then display on OLED and make them choose which one they want, also fix logic on invalid and ambiogous requests. Added Text on Oled
    [main.py]
2026-05-25 more game_id flow from the pico so it works
2026-06-13 minor folder rename and Readme improvement
    [bishop.stl, disk.stl, king.stl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]
2026-06-13 bom update
2026-06-17 Fix some changes
    [.step, top-plate.stl]
